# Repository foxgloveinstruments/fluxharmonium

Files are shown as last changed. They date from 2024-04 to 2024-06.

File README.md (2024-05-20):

# fluxharmonium
hardware and software for the fluxharmonium

## Hardware

Hardware design files for the primary electronics are located in the `kicad` of each primary function; [conductor](hardware/conductor/kicad), [ensemble](hardware/ensemble/kicad/), and [output](hardware/output/kicad).

## Software

The embedded microcontroller is currently a [Pimoroni Tiny2040 8MB](https://shop.pimoroni.com/products/tiny-2040) running CircuitPython. Firmware for the controller is located in the [src folder](src/)

Tested with Adafruit CircuitPython 8.0.5 on 2023-03-31; Pimoroni Tiny 2040 (8MB) with rp2040

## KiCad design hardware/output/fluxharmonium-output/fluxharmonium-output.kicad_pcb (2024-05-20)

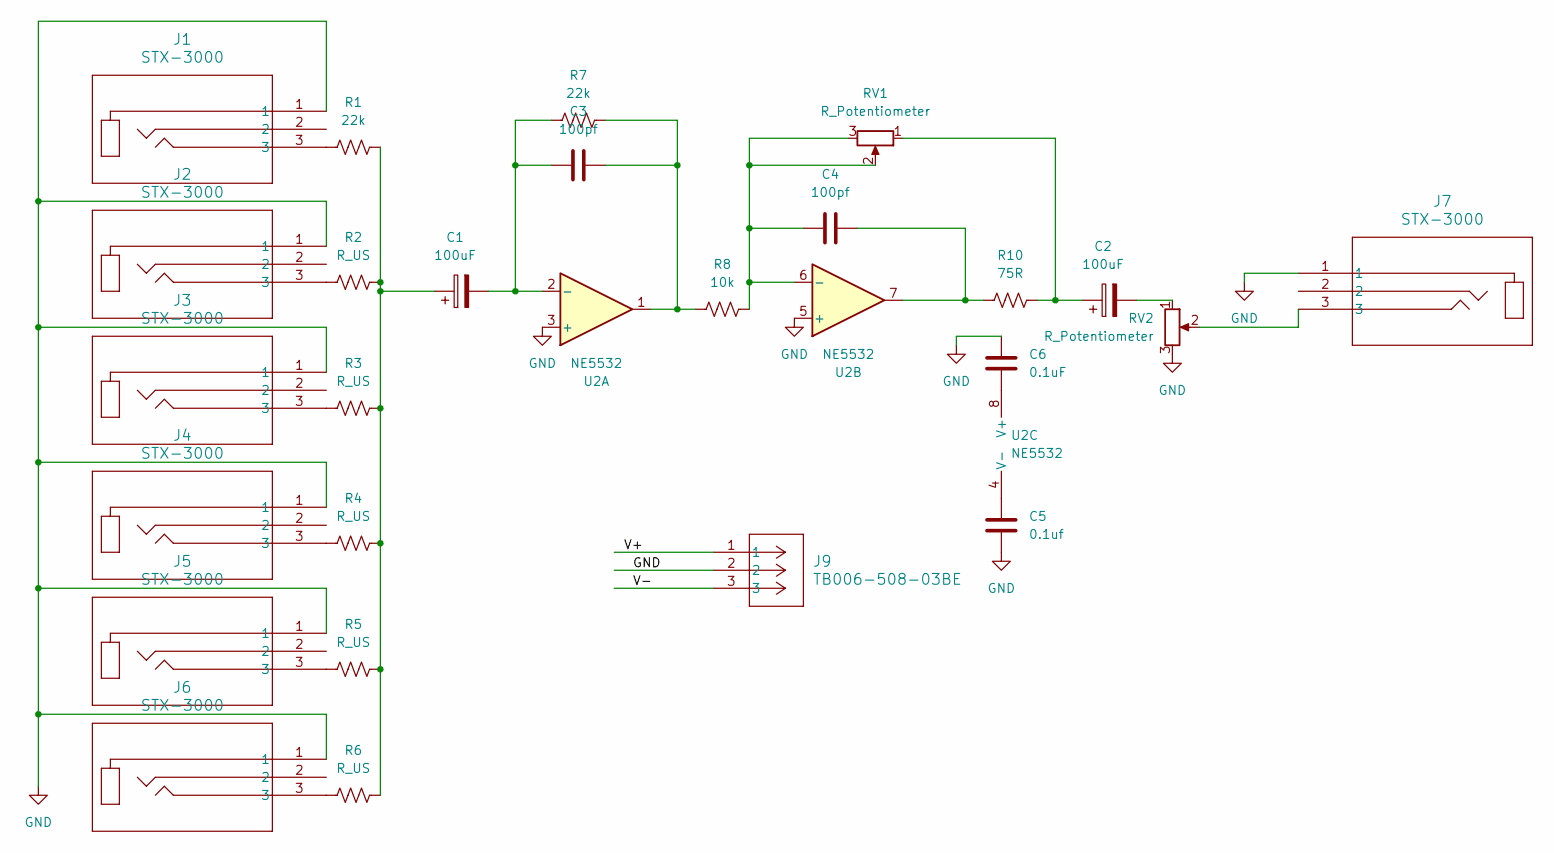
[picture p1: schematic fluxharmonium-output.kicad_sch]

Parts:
C1, C2: 100uF; CP_Radial_D5.0mm_P2.00mm
C3, C4: 100pf; C_Rect_L4.6mm_W2.0mm_P2.50mm_MKS02_FKP02
C5: 0.1uf; C_Disc_D3.8mm_W2.6mm_P2.50mm
C6: 0.1uF; C_Disc_D3.8mm_W2.6mm_P2.50mm
J1, J2, J3, J4, J5, J6, J7: STX-3000; STX-3000_KYC
J9: TB006-508-03BE; CONN3_TB006-508_CUD
R1, R7: 22k; R_Axial_DIN0207_L6.3mm_D2.5mm_P10.16mm_Horizontal
R2, R3, R4, R5, R6: R_US; R_Axial_DIN0207_L6.3mm_D2.5mm_P10.16mm_Horizontal
R8: 10k; R_Axial_DIN0207_L6.3mm_D2.5mm_P10.16mm_Horizontal
R10: 75R; R_Axial_DIN0207_L6.3mm_D2.5mm_P10.16mm_Horizontal
RV1: R_Potentiometer; Potentiometer_Bourns_3386P_Vertical
RV2: R_Potentiometer; PinSocket_1x03_P2.54mm_Vertical
U2: NE5532; DIP-8_W7.62mm

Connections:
/V+: J9.1
/V-: J9.3
GND: C5.1, C6.2, J1.1, J2.1, J3.1, J4.1, J5.1, J6.1, J7.1, J9.2, RV2.3, U2.3 (+), U2.5 (+)
unnamed: C1.1, R1.2, R2.2, R3.2, R4.2, R5.2, R6.2
unnamed: C2.1, R10.2, RV1.1
unnamed: C2.2, RV2.1
unnamed: C3.2, R7.2, R8.1, U2.1
unnamed: C4.2, R10.1, U2.7
unnamed: J1.3, R1.1
unnamed: J2.3, R2.1
unnamed: J3.3, R3.1
unnamed: J4.3, R4.1
unnamed: J5.3, R5.1
unnamed: J6.3, R6.1
unnamed: J7.3, RV2.2
unnamed: C1.2, C3.1, R7.1, U2.2 (-)
unnamed: C4.1, R8.2, RV1.2, RV1.3, U2.6 (-)
unnamed: C6.1, U2.8 (V+)
unnamed: C5.2, U2.4 (V-)

Board: 2 copper layers, 26 parts (0 on the bottom side), 17 nets, no tracks yet.

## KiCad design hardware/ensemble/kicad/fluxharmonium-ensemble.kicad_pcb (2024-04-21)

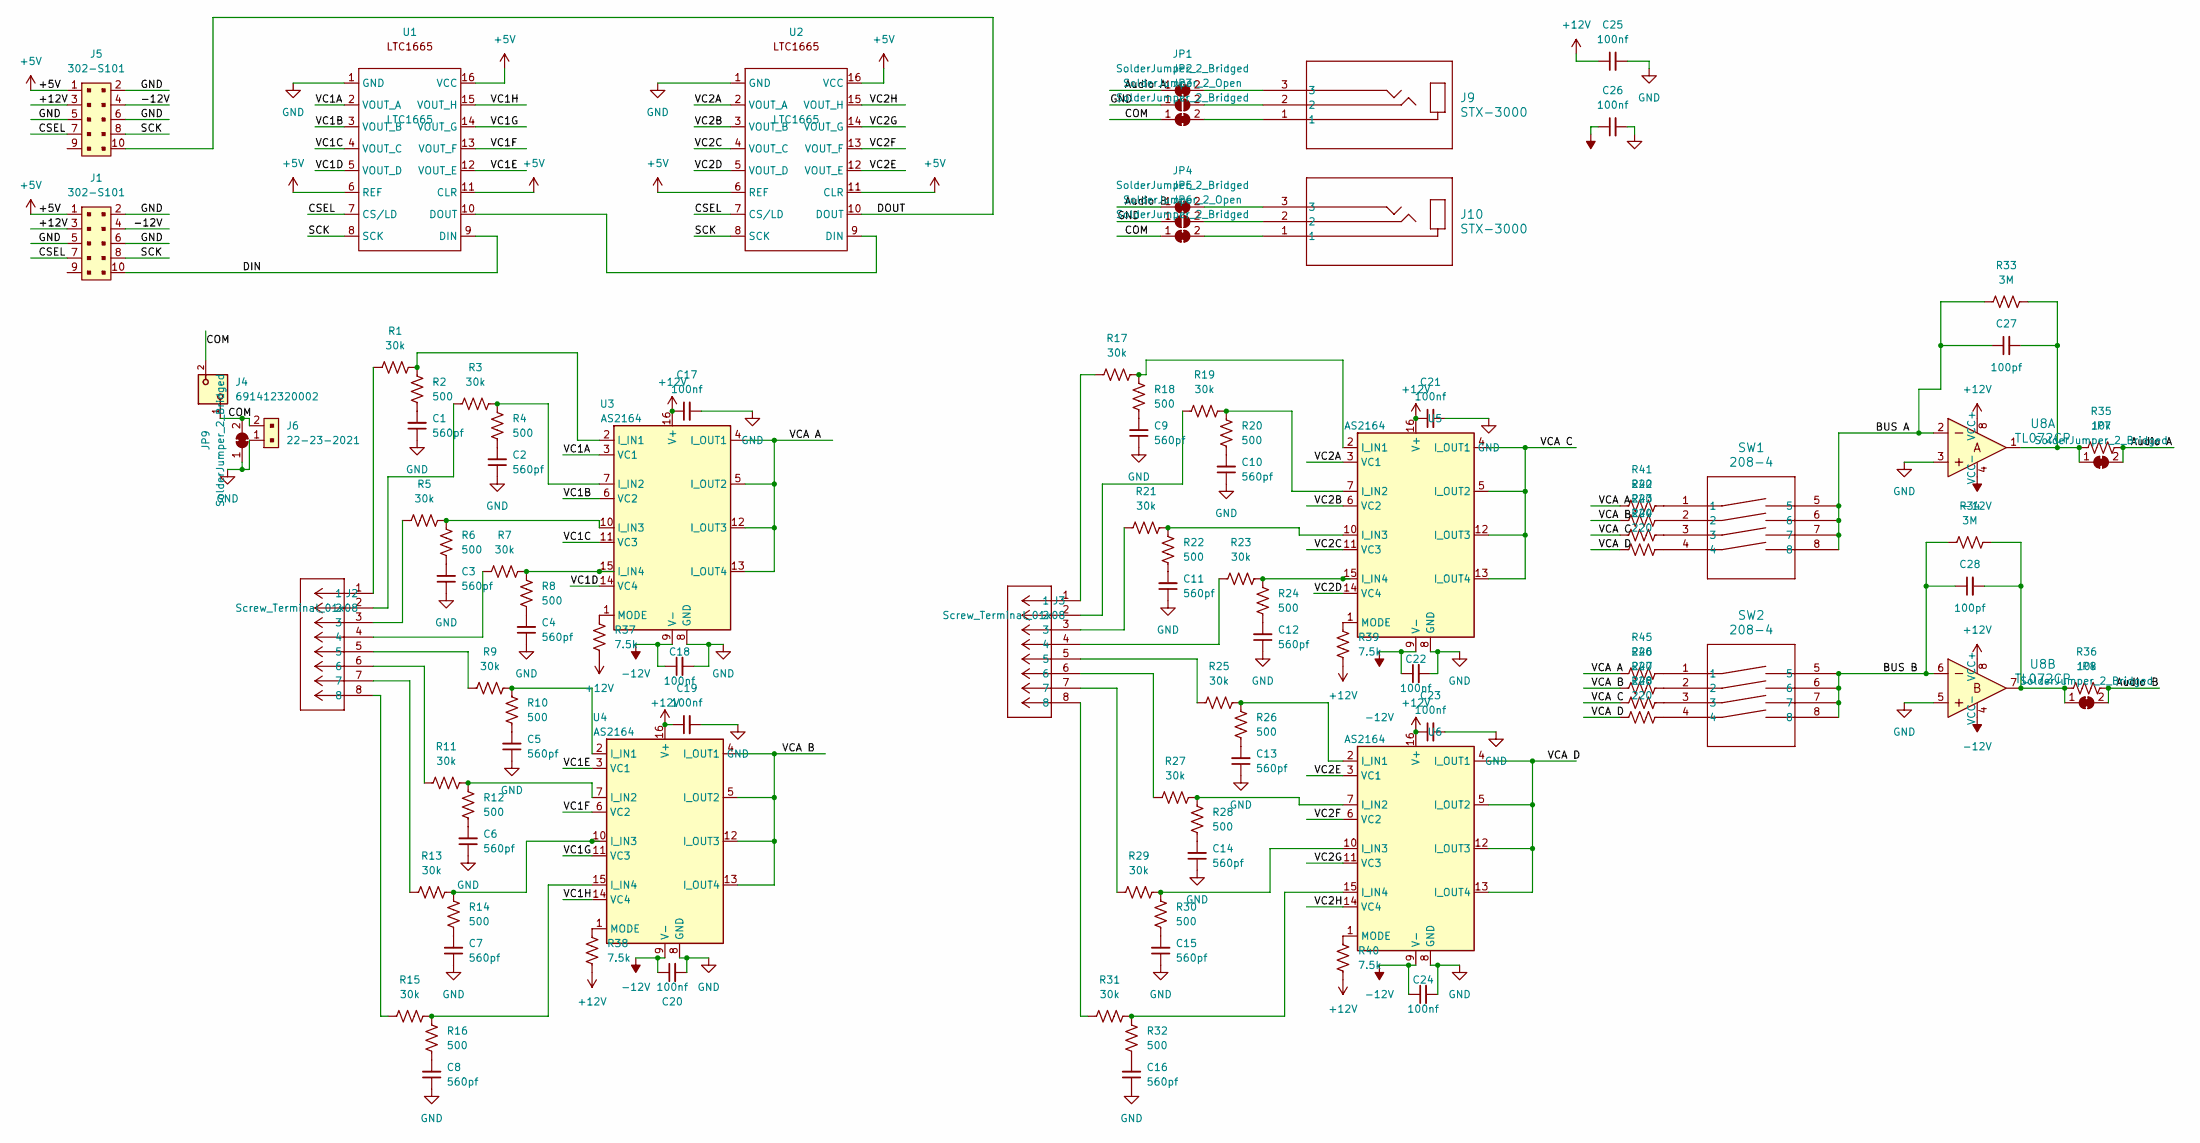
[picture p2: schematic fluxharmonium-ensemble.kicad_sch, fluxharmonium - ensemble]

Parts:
C1, C2, C3, C4, C5, C6, C7, C8, C9, C10, C11, C12, C13, C14, C15, C16: 560pf; C_Disc_D3.0mm_W2.0mm_P2.50mm
C17, C18, C19, C20, C21, C22, C23, C24, C25, C26: 100nf; C_Disc_D3.8mm_W2.6mm_P2.50mm
C27, C28: 100pf; C_Disc_D3.8mm_W2.6mm_P2.50mm
J1, J5: 302-S101; IDC-Header_2x05_P2.54mm_Latch_Vertical; MPN 302-S101; Digi-Key_PN ED1543-ND
J2, J3: Screw_Terminal_01x08; CONN_1755794_PXC
J4: 691412320002; PART-NUMBER 691412320002
J6: 22-23-2021; PinHeader_1x2_P2.54mm_Drill1.02mm; MPN 22-23-2021; Digi-Key_PN WM4200-ND
J9, J10: STX-3000; xess-STX-3000_KYC
JP1, JP3, JP4, JP6, JP7, JP8, JP9: SolderJumper_2_Bridged; SolderJumper-2_P1.3mm_Bridged_RoundedPad1.0x1.5mm
JP2, JP5: SolderJumper_2_Open; SolderJumper-2_P1.3mm_Open_RoundedPad1.0x1.5mm
R1, R3, R5, R7, R9, R11, R13, R15, R17, R19, R21, R23, R25, R27, R29, R31: 30k; R_Axial_DIN0207_L6.3mm_D2.5mm_P2.54mm_Vertical
R2, R4, R6, R8, R10, R12, R14, R16, R18, R20, R22, R24, R26, R28, R30, R32: 500; R_Axial_DIN0207_L6.3mm_D2.5mm_P2.54mm_Vertical
R33, R34: 3M; R_Axial_DIN0207_L6.3mm_D2.5mm_P2.54mm_Vertical
R35, R36: 10k; R_Axial_DIN0207_L6.3mm_D2.5mm_P2.54mm_Vertical
R37, R38, R39, R40: 7.5k; R_Axial_DIN0207_L6.3mm_D2.5mm_P2.54mm_Vertical
R41, R42, R43, R44, R45, R46, R47, R48: 220; R_Axial_DIN0207_L6.3mm_D2.5mm_P2.54mm_Vertical
SW1, SW2: 208-4; DIP8_208-4_CTS
U1, U2: LTC1665; DIP-16_W7.62mm_LongPads
U3, U4, U5, U6: AS2164; DIP-16_W7.62mm_LongPads
U8: TL072CP; DIP-8_W7.62mm; MPN TL072CP; Digi-Key_PN 296-1775-5-ND

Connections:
+5V: J1.1, J5.1, U1.6 (REF), U1.11 (CLR), U1.16 (VCC), U2.6 (REF), U2.11 (CLR), U2.16 (VCC)
+12V: C17.1, C19.1, C21.1, C23.1, C25.1, J1.3, J5.3, R37.1, R38.1, R39.1, R40.1, U3.16 (V+), U4.16 (V+), U5.16 (V+), U6.16 (V+), U8.8 (VCC+)
-12V: C18.1, C20.1, C22.1, C24.1, C26.1, J1.4, J5.4, U3.9 (V-), U4.9 (V-), U5.9 (V-), U6.9 (V-), U8.4 (VCC-)
/Audio A: JP1.1 (A), JP7.2 (B), R35.2
/Audio B: JP4.1 (A), JP8.2 (B), R36.2
/BUS A: C27.1, R33.1, SW1.5, SW1.6, SW1.7, SW1.8, U8.2
/BUS B: C28.1, R34.1, SW2.5, SW2.6, SW2.7, SW2.8, U8.6
/COM: J4.1, J4.2, J6.2, JP3.1 (A), JP6.1 (A), JP9.2 (B)
/CSEL: J1.7, J5.7, U1.7 (CS/LD), U2.7 (CS/LD)
/DIN: J1.10, U1.9 (DIN)
/DOUT: J5.10, U2.10 (DOUT)
/SCK: J1.8, J5.8, U1.8 (SCK), U2.8 (SCK)
/VC1A: U1.2 (VOUT_A), U3.3 (VC1)
/VC1B: U1.3 (VOUT_B), U3.6 (VC2)
/VC1C: U1.4 (VOUT_C), U3.11 (VC3)
/VC1D: U1.5 (VOUT_D), U3.14 (VC4)
/VC1E: U1.12 (VOUT_E), U4.3 (VC1)
/VC1F: U1.13 (VOUT_F), U4.6 (VC2)
/VC1G: U1.14 (VOUT_G), U4.11 (VC3)
/VC1H: U1.15 (VOUT_H), U4.14 (VC4)
/VC2A: U2.2 (VOUT_A), U5.3 (VC1)
/VC2B: U2.3 (VOUT_B), U5.6 (VC2)
/VC2C: U2.4 (VOUT_C), U5.11 (VC3)
/VC2D: U2.5 (VOUT_D), U5.14 (VC4)
/VC2E: U2.12 (VOUT_E), U6.3 (VC1)
/VC2F: U2.13 (VOUT_F), U6.6 (VC2)
/VC2G: U2.14 (VOUT_G), U6.11 (VC3)
/VC2H: U2.15 (VOUT_H), U6.14 (VC4)
/VCA A: R41.1, R45.1, U3.4 (I_OUT1), U3.5 (I_OUT2), U3.12 (I_OUT3), U3.13 (I_OUT4)
/VCA B: R42.1, R46.1, U4.4 (I_OUT1), U4.5 (I_OUT2), U4.12 (I_OUT3), U4.13 (I_OUT4)
/VCA C: R43.1, R47.1, U5.4 (I_OUT1), U5.5 (I_OUT2), U5.12 (I_OUT3), U5.13 (I_OUT4)
/VCA D: R44.1, R48.1, U6.4 (I_OUT1), U6.5 (I_OUT2), U6.12 (I_OUT3), U6.13 (I_OUT4)
GND: C1.1, C2.1, C3.1, C4.1, C5.1, C6.1, C7.1, C8.1, C9.1, C10.1, C11.1, C12.1, C13.1, C14.1, C15.1, C16.1, C17.2, C18.2, C19.2, C20.2, C21.2, C22.2, C23.2, C24.2, C25.2, C26.2, J1.2, J1.5, J1.6, J5.2, J5.5, J5.6, J6.1, JP2.1 (A), JP5.1 (A), JP9.1 (A), U1.1 (GND), U2.1 (GND), U3.8 (GND), U4.8 (GND), U5.8 (GND), U6.8 (GND), U8.3, U8.5
unnamed: C1.2, R2.1
unnamed: C2.2, R4.1
unnamed: C3.2, R6.1
unnamed: C4.2, R8.1
unnamed: C5.2, R10.1
unnamed: C6.2, R12.1
unnamed: C7.2, R14.1
unnamed: C8.2, R16.1
unnamed: C9.2, R18.1
unnamed: C10.2, R20.1
unnamed: C11.2, R22.1
unnamed: C12.2, R24.1
unnamed: C13.2, R26.1
unnamed: C14.2, R28.1
unnamed: C15.2, R30.1
unnamed: C16.2, R32.1
unnamed: J2.1, R1.1
unnamed: J2.2, R3.1
unnamed: J2.3, R5.1
unnamed: J2.4, R7.1
unnamed: J2.5, R9.1
unnamed: J2.6, R11.1
unnamed: J2.7, R13.1
unnamed: J2.8, R15.1
unnamed: J3.1, R17.1
unnamed: J3.2, R19.1
unnamed: J3.3, R21.1
unnamed: J3.4, R23.1
unnamed: J3.5, R25.1
unnamed: J3.6, R27.1
unnamed: J3.7, R29.1
unnamed: J3.8, R31.1
unnamed: J9.3, JP1.2 (B)
unnamed: J9.2, JP2.2 (B)
unnamed: J9.1, JP3.2 (B)
unnamed: J10.3, JP4.2 (B)
unnamed: J10.2, JP5.2 (B)
unnamed: J10.1, JP6.2 (B)
unnamed: C27.2, JP7.1 (A), R33.2, R35.1, U8.1
unnamed: C28.2, JP8.1 (A), R34.2, R36.1, U8.7
unnamed: R41.2, SW1.1
unnamed: R42.2, SW1.2
unnamed: R43.2, SW1.3
unnamed: R44.2, SW1.4
unnamed: R45.2, SW2.1
unnamed: R46.2, SW2.2
unnamed: R47.2, SW2.3
unnamed: R48.2, SW2.4
unnamed: U1.10 (DOUT), U2.9 (DIN)
unnamed: R1.2, R2.2, U3.2 (I_IN1)
unnamed: R3.2, R4.2, U3.7 (I_IN2)
unnamed: R5.2, R6.2, U3.10 (I_IN3)
unnamed: R7.2, R8.2, U3.15 (I_IN4)
unnamed: R37.2, U3.1 (MODE)
unnamed: R9.2, R10.2, U4.2 (I_IN1)
unnamed: R11.2, R12.2, U4.7 (I_IN2)
unnamed: R13.2, R14.2, U4.10 (I_IN3)
unnamed: R15.2, R16.2, U4.15 (I_IN4)
unnamed: R38.2, U4.1 (MODE)
unnamed: R17.2, R18.2, U5.2 (I_IN1)
unnamed: R19.2, R20.2, U5.7 (I_IN2)
unnamed: R21.2, R22.2, U5.10 (I_IN3)
unnamed: R23.2, R24.2, U5.15 (I_IN4)
unnamed: R39.2, U5.1 (MODE)
unnamed: R25.2, R26.2, U6.2 (I_IN1)
unnamed: R27.2, R28.2, U6.7 (I_IN2)
unnamed: R29.2, R30.2, U6.10 (I_IN3)
unnamed: R31.2, R32.2, U6.15 (I_IN4)
unnamed: R40.2, U6.1 (MODE)

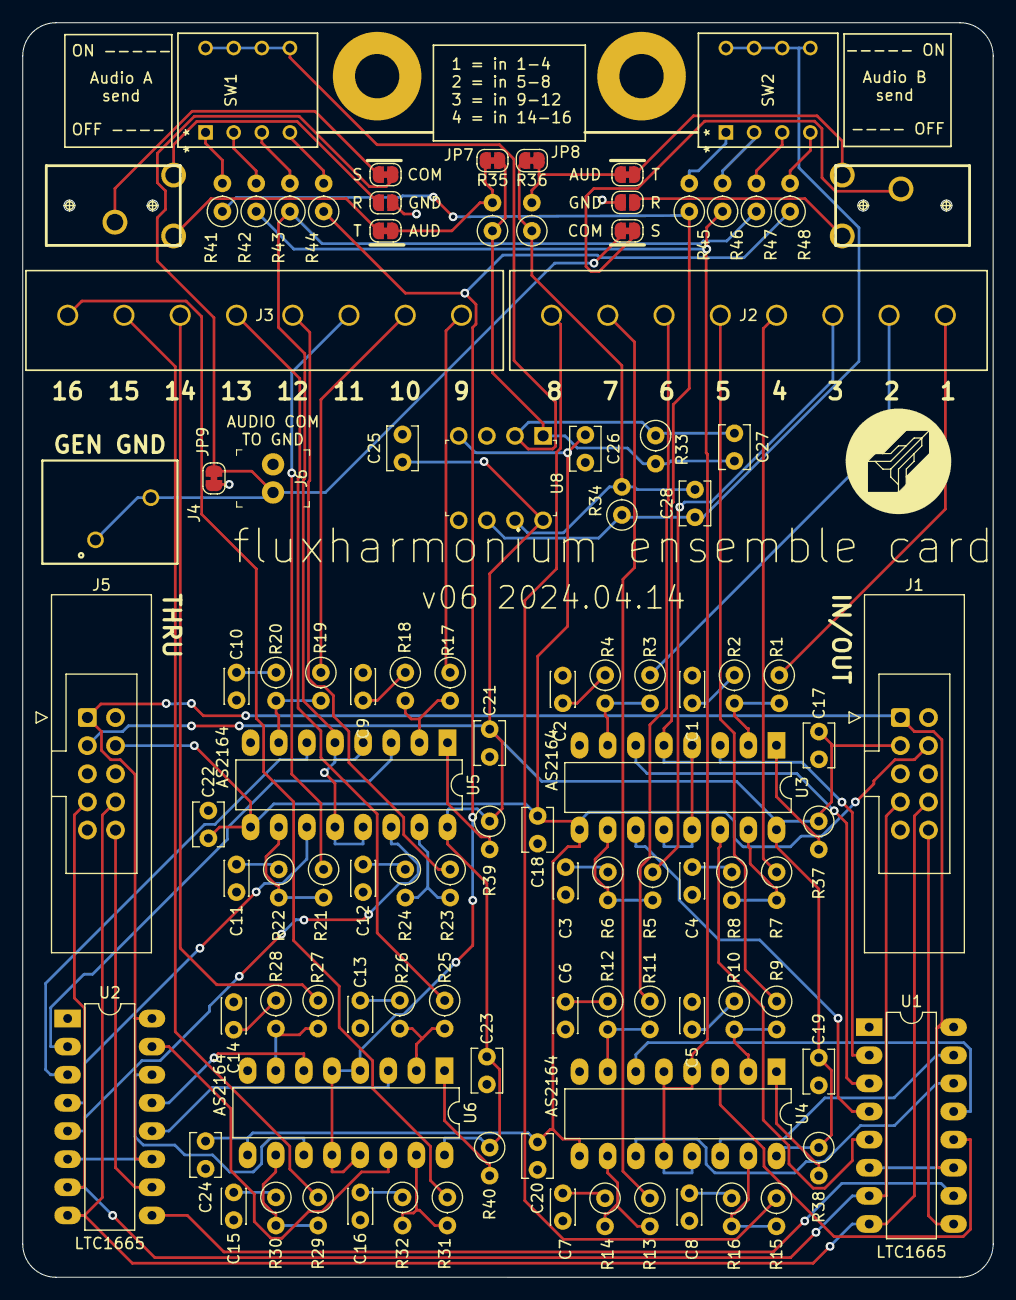
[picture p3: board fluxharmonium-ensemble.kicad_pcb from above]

Board: 2 copper layers, 87.6 x 113.3 mm, 104 parts (0 on the bottom side), 102 nets.

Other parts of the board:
Hole1, Hole2: MountingHole_4mm_Pad

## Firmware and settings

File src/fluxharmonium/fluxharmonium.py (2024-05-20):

"""
fluxharmonium MIDI and envelope processing.
Sends final DAC values to rp2040 for applying to SPI DACs using usb_cdc 

See https://github.com/Neradoc/circuitpython-sample-scripts/blob/main/usb_serial/serial_send-host.py for sending
See https://github.com/Neradoc/circuitpython-sample-scripts/blob/main/usb_serial/serial_send_data-code.py for receiving on the rp2040 side


# To send data to the rp2040 the dac_values need to be flattened and made into a bytes list.

from itertools import chain

dac_values = [[255, 133, 122], [255, 128, 65]]
bytes_values = bytes(list(chain.from_iterable(dac_values)))

print(f'in bytes: {bytes_values}')

dependencies:
  adsr.py - envelope definition
  config.py - Global Config params
  control_loop.py - asyncio loops
  dacs.py - calculates the correct value for the DAC (velocity*env) 
  envelopes.py - processes envelopes for each note
  note_map.py - maps MIDI notes to tonegenerator outputs

requirements:
  mido
  itertools
  serial
"""

import asyncio
import argparse
from itertools import chain
import logging
import mido
import serial
import sys
import time

from config import *
from note_map import *

import adsr
import control_loop
import dacs
import envelopes as eg


class FluxProcessor:
  def __init__(self):
    self._logger = logging.getLogger('fluxharmonium')  
    
    self.midi_port = MIDI_PORT
    self.midi_in = None

    self.serial_port = SERIAL_PORT
    self.channel = None

    self.velocity_values = [0] * NUMBER_OF_NOTES
    self.envelope_values = [0] * NUMBER_OF_NOTES
    
    self.envelopes = None
    self.dacs = None

    self.last_dacs = None
    
    self.control_loop = control_loop.ControlLoop(self, CONTROL_RATE)
    
    self.running = False

  def initEnvelopes(self):
    self.envelopes = eg.Envelopes(self, CONTROL_RATE, self.envelope_values)
    for e in range(NUMBER_OF_NOTES):
        self.envelopes.add_envelope(adsr.ADSR(0.1, 0.05, 1, 1, CONTROL_RATE))
  
  def initDACs(self):
    self.dacs = dacs.DACs(self, CONTROL_RATE, self.envelope_values, self.velocity_values)
    
  def run(self):
    if self.serial_port:
      self.start_serial(self.serial_port)
    if self.midi_port:
      self.start_midi(self.midi_port)
      # pass

    self.initEnvelopes()
    self.initDACs()
    
    self.running = True
    
    self._logger.info(f'--------------------------')
    self._logger.info(f'fluxharmonium running...')
    self._logger.info(f'--------------------------')

    self._logger.debug(f'{self.control_loop}')

    self.control_loop.add_control(self.envelopes.run())
    self.control_loop.add_control(self.dacs.run())

    self._logger.debug(f'control loops started')
    
    while self.running:
        self._logger.debug(f'running')
        try:
          asyncio.run(self.control_loop.run())
        except KeyboardInterrupt:
          self._logger.info("fluxharmonium terminated...shutting down")
        finally:
          self.control_loop.stop()
          self.midi_in.close()
          self.channel.close()
          sys.exit('see ya next time')
    

  def start_serial(self, port):
    try:
      self._logger.info(f'opening serial port {port}')
      self.channel = serial.Serial(port, 115200, dsrdtr=True)
      self.channel.timeout = 0.05
      self.channel.write_timeout = 0.2
      self._logger.debug(f'serial channel {self.channel}')
      self._logger.debug(f'serial DTR state {self.channel.dtr}')
    except (EOFError, KeyboardInterrupt):
      self._logger.error(f'Serial device {port} failed to initialize')
      sys.exit(1)
    
  def start_midi(self, port):
    try:
      self._logger.info(f'opening MIDI port {port}')

      # mido.set_backend('mido.backends.rtmidi', load=True)
      # mido.set_backend('mido.backends.rtmidi/LINUX_ALSA', load=True)

      self._logger.debug(f'mido backend {mido.backend}')
      self._logger.debug(f'mido available APIs {mido.backend.module.get_api_names()}')
      self._logger.debug(f'MIDI inputs {mido.get_input_names()}')
      

      self.midi_in = mido.open_input(port, callback=self.parse_midi)  
    except (EOFError, KeyboardInterrupt):
      self._logger.error(f'MIDI device {port} failed to initialize')
      sys.exit(1)

  def parse_midi(self, msg):
    # self._logger.debug(f'MIDI message received: {msg}')
    if msg.type == 'note_on':
      self._logger.debug(f'Note On received: {msg}')
      note_index = msg.note - MIDI_LOW_VALUE
      self.velocity_values[note_index] = msg.velocity
      self.envelopes.envelopes[note_index].gate(1)

    elif msg.type == 'note_off':
      self._logger.debug(f'Note Off received: {msg}')
      note_index = msg.note - MIDI_LOW_VALUE
      self.envelopes.envelopes[note_index].gate(0)

    elif msg.type == 'control_change':
      """
      Volume and Envelope settings per note.
      """
      self._logger.debug(f'Control Change received: {msg}')
      if msg.channel == OUT_VOL_CHAN and msg.control >= MIDI_LOW_VALUE:
          # Process Dynamic Volume Control
          control_index = msg.control - MIDI_LOW_VALUE
          self.velocity_values[control_index] = msg.value
      elif msg.channel == ENV_MODE_CHAN and msg.control == ENV_MODE_CTRL:
          # Process Envelope Mode Control
          pass
      elif msg.channel == ENV_ATTACK_CHAN and msg.control >= MIDI_LOW_VALUE:
          # Process Envelope Attack Control
          note_index = msg.control - MIDI_LOW_VALUE
          self.envelopes.envelopes[note_index].update_attack(msg.value/CTRL_SEC_DIV)
      elif msg.channel == ENV_RELEASE_CHAN and msg.control >= MIDI_LOW_VALUE:
          # Process Envelope Release Control
          note_index = msg.control - MIDI_LOW_VALUE
          self.envelopes.envelopes[note_index].update_release(msg.value/CTRL_SEC_DIV)
    elif msg.type == 'aftertouch':
      pass
    elif msg.type == 'polytouch':
      pass
  
  def send_dac_values(self, dac_values):
    byte_values = bytes(list(chain.from_iterable(dac_values)))

    if byte_values != self.last_dacs:
      self.last_dacs = byte_values
      # self._logger.debug(f'serial is open {self.channel.isOpen()}')
      self._logger.debug(f'sending dac values {dac_values}')
      self.channel.reset_output_buffer()
      self._logger.debug(f'outbuffer {self.channel.out_waiting}')
      
      try:
        self.channel.write(byte_values)
        self.channel.write(b'\r\n')
        self._logger.debug(f'finished sending')
      except Exception as e:
        self._logger.error(f'Error sending dac values {e}')

def main():
  parser = argparse.ArgumentParser()
  parser.add_argument('-v', action='count', dest='verbosity', default=0,
                      help='Increase logging verbosity level (-v or -vv)')
  args = parser.parse_args()
  
  log_level = logging.WARNING
  if args.verbosity == 1:
    log_level = logging.INFO
  elif args.verbosity >= 2:
    log_level = logging.DEBUG
    
  logging.basicConfig(format='[%(levelname)s] {%(filename)s:%(lineno)d} %(message)s', level=log_level)
    
  fluxprocessor = FluxProcessor()
  time.sleep(2)
  fluxprocessor.run()

if __name__ == '__main__':
  main()

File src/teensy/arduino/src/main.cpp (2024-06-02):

#include <Arduino.h>
#include <SPI.h>
#include <chrono>

#include <TeensyThreads.h>
// this method is experimental
ThreadWrap(Serial, SerialXtra);
#define Serial ThreadClone(SerialXtra)

#include "config.h"
#include "noteMap.h"

#include "dacs.h"
#include "adsr.h"

#define DEBUG true

const int yield_time = int((1.0/1)*1000);


uint8_t velocity_values[NUMBER_OF_NOTES];
float envelope_values[NUMBER_OF_NOTES];

DACs dacs(&envelope_values[0], &velocity_values[0], DEBUG);
std::vector<ADSR> envelopes(NUMBER_OF_NOTES, ADSR(0.01f, 0.0f, 1.0f, 0.1f, CONTROL_RATE_Hz));

int env_thread_id;
int dac_thread_id;

void printEnvelopes() {
  Serial.println("env_values: ");
    Serial.print("[");
    for (int i=0; i<NUMBER_OF_NOTES;i++){
        Serial.print(envelope_values[i]);
        Serial.print(",");
    }
    Serial.println("]");
    Serial.println("");
    Serial.println("");
}

void NoteOn(byte channel, byte note, byte velocity) {
  // DEBUG = true;
  uint8_t note_index = note - MIDI_LOW_VALUE;
  velocity_values[note_index] = velocity;
  envelopes[note_index].gate(1);
  if (DEBUG) {
    Serial.printf("Note ON channel: %d note: %d vel: %d\n", channel, note, velocity);
    printEnvelopes();
    dacs.printDacs();
  }
}
void NoteOff(byte channel, byte note, byte velocity) {
  uint8_t note_index = note - MIDI_LOW_VALUE;
  envelopes[note_index].gate(0);
  if (DEBUG) {
    Serial.printf("Note OFF channel: %d note: %d vel: %d\n", channel, note, velocity);
    printEnvelopes();
    dacs.printDacs();
  }
  // DEBUG = false;
}

void envelope_run() {
  while(1) {
    Serial.println("running envelopes");
    for(uint16_t env=0;env< envelopes.size();env++) {
          float env_val = envelopes[env].val;
          envelope_values[env] = env_val;
      }

    for(ADSR& adsr : envelopes) {
        ++adsr.begin();  // Get iterator from ADSR
    }

    if (DEBUG) {
      // printEnvelopes();
    }

    threads.delay(yield_time);
  }
}

void dac_run() {
  while(1) {
    Serial.println("running dacs");
    dacs.run();
    threads.delay(yield_time);
  }
}

void midi_run() {
  while(1) {
    usbMIDI.read();
    Serial.printf("ENV thread is %d\n", threads.getState(env_thread_id));
    Serial.printf("DAC thread is %d\n", threads.getState(dac_thread_id));
    threads.delay(yield_time);
  }
}


void setup() {
  // if (DEBUG) {
    Serial.begin(9600);
    Serial.println("Hello teensy");
    Serial.printf("yield time: %d ms\n", yield_time);
  // }

  usbMIDI.setHandleNoteOn(NoteOn);
  usbMIDI.setHandleNoteOff(NoteOff);
  delay(1000);


  dacs.init();
  
  delay(1000);
  // Run threads
  env_thread_id = threads.addThread(envelope_run);
  dac_thread_id = threads.addThread(dac_run);
  threads.addThread(midi_run);


  Serial.println("All started....");
}

void loop() {
  // usbMIDI.read();
  
}

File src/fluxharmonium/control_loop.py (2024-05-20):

import asyncio

class ControlLoop:
    def __init__(self, parent, _frequency=200):
        self.parent = parent
        self.frequency = _frequency
        self.controls = []
        self.control_tasks = []
        self.event_loop = asyncio.get_event_loop()

    async def run(self):
        self.parent._logger.debug(f'running event loop')
        for control in self.controls:
            task = asyncio.create_task(control)
            self.control_tasks.append(task)
            asyncio.ensure_future(task)
        await asyncio.gather(*(c for c in self.control_tasks)) 

    def stop(self):
        self.event_loop.stop()
        self.parent._logger.debug(f'stopped event loop')

    def freq_to_ms(self, freq):
        return 1000/freq

    def freq_to_sec(self, freq):
        return 1000/1000/freq

    def add_control(self, control):
        self.controls.append(control)

    def output_control(self, value):
        print(value)

    async def update(self):
        for control in self.controls:
            control_value = next(control)
            self.output_control(control_value)
        # Is this the most accurate timing for coroutines ?
        await asyncio.sleep(self.freq_to_sec(self.frequency))

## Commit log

2024-04-21 Added v6 hardware and firmware
    [fluxharmonium-ensemble.kicad_pcb, fluxharmonium-ensemble.kicad_sch]
2024-05-20 Split to various versions for different hardware
    [fluxharmonium-output.kicad_pcb, fluxharmonium-output.kicad_sch]
